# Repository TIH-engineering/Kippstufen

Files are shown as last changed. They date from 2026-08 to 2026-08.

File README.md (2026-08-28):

# Kippstufen






## 🔌 Leiterplattenbeschreibung

Die Leiterplatte **Kippstufen** dient zur Untersuchung verschiedener digitaler Grundschaltungen und Kippstufen. Sie wurde insbesondere für den Einsatz im Elektroniklabor und zur praktischen Ergänzung des Unterrichts entwickelt.

Auf der Leiterplatte sind unterschiedliche Schaltungsvarianten realisiert:

- **diskret aufgebaute Kippstufen** mit Transistoren
- **Kippstufe mit NE555-Timer**
- **bistabile Kippstufe** mit Logik-IC
- **monostabile Kippstufe** mit Logik-IC
- **astabile Kippstufe** mit Logik-IC

Über Taster und Steckverbinder können die Schaltungen angesteuert und unterschiedliche Betriebsarten untersucht werden. LEDs dienen zur optischen Anzeige der jeweiligen Ausgangszustände.

Bei der diskret aufgebauten Kippstufe ermöglichen Jumper die Konfiguration als **bistabile, monostabile oder astabile Kippstufe**. Zusätzlich sind Messanschlüsse vorgesehen, unter anderem zur Untersuchung der Kondensatorspannungen.

Die Leiterplatte eignet sich damit zur praktischen Untersuchung von **Schaltzuständen, Zeitverhalten, Rückkopplung und Oszillation** bei unterschiedlichen Realisierungen von Kippstufen.

> **Einsatzgebiet:** Laborübungen und Unterricht im Bereich Digitaltechnik / Elektronik

---

## 📥 Downloads

| Datei | Beschreibung |
|---|---|
| 📄 [Schaltplan (PDF)](../../releases/latest/download/schematic.pdf) | Schaltplan der Leiterplatte |
| 🖨️ [Leiterplatte (PDF)](../../releases/latest/download/pcb.pdf) | Leiterplattenansicht als PDF |
| 🔩 [Bohrplan (PDF)](../../releases/latest/download/drill.pdf) | Bohrdaten / Bohrplan |
| 📋 [Stückliste (Excel)](../../releases/latest/download/bom.xlsx) | Bill of Materials |
| 🌐 [Interactive BOM](../../releases/latest/download/ibom.html) | Interaktive Bestückungsansicht |
| 📦 [Fertigungsdaten](../../releases/latest/download/kicad.zip) | Gerber- und Bohrdaten |
| 🧊 [STEP-Modell](../../releases/latest/download/pcb.step) | 3D-Modell der Leiterplatte |

Die Dateien werden automatisch durch den Release-Workflow erzeugt.

---

## 🖥️ Leiterplatte

### Vorschau

| Oberseite | Unterseite |
|:---:|:---:|
| PCB Top | PCB Bottom |

### Oberseite

PCB Top

### Unterseite

PCB Bottom

---

## ℹ️ Projektinformationen

| Eigenschaft | Wert |
|---|---|
| **Projekt** | Kippstufen |
| **Software** | KiCad 10 |
| **Repository** | TIH-engineering/Kippstufen |
| **Autor** | TIH |
| **Lizenz** | CC BY-NC-SA 4.0 |

---

## 🗂️ Repository-Struktur

```text
.
├── .github/
│   └── workflows/       # GitHub Actions
├── .kibot/              # KiBot-Konfiguration
├── pcb/
│   ├── lib/             # Projektspezifische Bibliotheken
│   └── ...              # KiCad-Projektdateien
├── .gitignore
├── LICENSE
└── README.md

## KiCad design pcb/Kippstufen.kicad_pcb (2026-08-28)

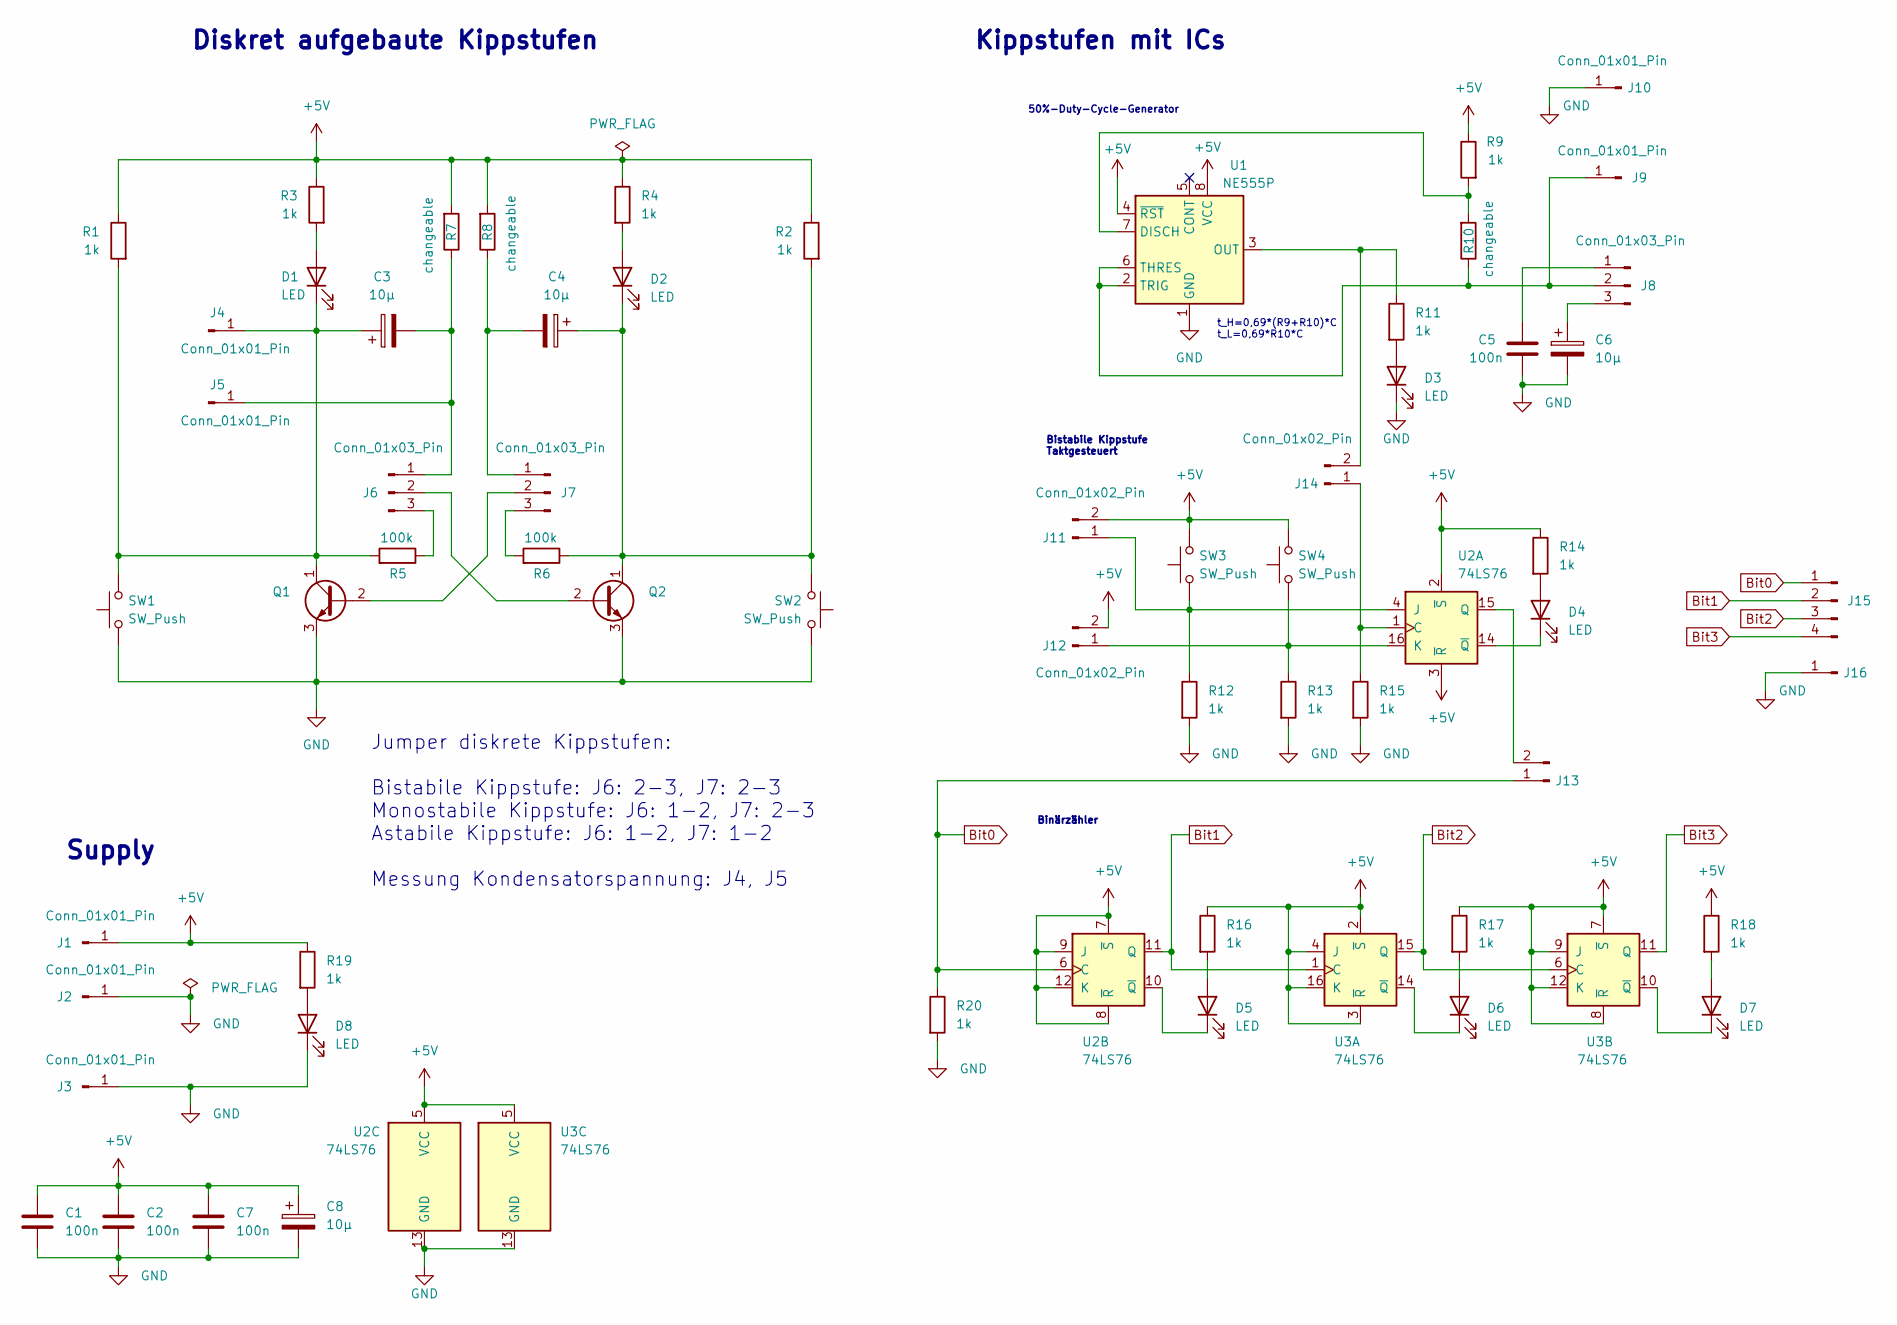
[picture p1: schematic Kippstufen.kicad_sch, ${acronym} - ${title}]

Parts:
C1, C2, C5, C7: 100n; C_1206_3216Metric
C3, C4, C6, C8: 10µ; CP_Radial_D5.0mm_P2.00mm
D1, D2, D3, D4, D5, D6, D7, D8: LED; LED_1206_3216Metric
J1, J2, J3, J4, J5, J9, J10, J16: Conn_01x01_Pin; PinHeader_1x01_P2.54mm_Vertical
J6, J7, J8: Conn_01x03_Pin; PinHeader_1x03_P2.54mm_Vertical
J11, J12, J13, J14: Conn_01x02_Pin; PinHeader_1x02_P2.54mm_Vertical
J15: Conn_01x04_Pin; PinHeader_1x04_P2.54mm_Vertical
Q1, Q2: BC547; TO-92_Inline_Wide
R1, R2, R3, R4, R9, R11, R12, R13, R14, R15, R16, R17, R18, R19, R20: 1k; R_1206_3216Metric
R5, R6: 100k; R_1206_3216Metric
R7, R8, R10: 10k; R_axial_SMD-Adapter_P10.16mm_1mm
SW1, SW2, SW3, SW4: SW_Push; SW_Push_1P1T_NO_E-Switch_TL3301NxxxxxG
U1: NE555P; DIP-8_W7.62mm
U2, U3: 74LS76; DIP-16_W7.62mm

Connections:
+5V: C1.1, C2.1, C7.1, C8.1, J1.1 (Pin_1_1), J11.2, J12.2, R1.1, R2.1, R3.1, R4.1, R7.2, R8.2, R9.1, R14.1, R16.1, R17.1, R18.1, R19.1, SW3.2, SW4.2, U1.4 (~RST), U1.8 (VCC), U2.2 (~S), U2.3 (~R), U2.5 (VCC), U2.7 (~S), U2.8 (~R), U2.9 (J), U2.12 (K), U3.2 (~S), U3.3 (~R), U3.4 (J), U3.5 (VCC), U3.7 (~S), U3.8 (~R), U3.9 (J), U3.12 (K), U3.16 (K)
Bit0: J13.1, J15.1, R20.1, U2.6 (C)
Bit1: J15.2, U2.11 (Q), U3.1 (C)
Bit2: J15.3, U3.6 (C), U3.15 (Q)
Bit3: J15.4, U3.11 (Q)
GND: C1.2, C2.2, C5.2, C6.2, C7.2, C8.2, D3.1 (K), D8.1 (K), J2.1 (Pin_1_1), J3.1 (Pin_1_1), J10.1 (Pin_1_1), J16.1 (Pin_1_1), Q1.3 (E), Q2.3 (E), R12.2, R13.2, R15.2, R20.2, SW1.1, SW2.1, U1.1 (GND), U2.13 (GND), U3.13 (GND)
unnamed: D1.2 (A), R3.2
unnamed: C3.1, D1.1 (K), J4.1 (Pin_1_1), Q1.1 (C), R1.2, R5.2, SW1.2
unnamed: D2.2 (A), R4.2
unnamed: C4.1, D2.1 (K), Q2.1 (C), R2.2, R6.1, SW2.2
unnamed: D3.2 (A), R11.2
unnamed: D4.2 (A), R14.2
unnamed: D4.1 (K), U2.14 (~Q)
unnamed: D5.2 (A), R16.2
unnamed: D5.1 (K), U2.10 (~Q)
unnamed: D6.2 (A), R17.2
unnamed: D6.1 (K), U3.14 (~Q)
unnamed: D7.2 (A), R18.2
unnamed: D7.1 (K), U3.10 (~Q)
unnamed: D8.2 (A), R19.2
unnamed: C3.2, J5.1 (Pin_1_1), J6.1, R7.1
unnamed: J6.2, Q2.2 (B)
unnamed: J6.3, R5.1
unnamed: C4.2, J7.1, R8.1
unnamed: J7.2, Q1.2 (B)
unnamed: J7.3, R6.2
unnamed: C5.1, J8.1
unnamed: J8.2, J9.1 (Pin_1_1), R10.1, U1.2 (TRIG), U1.6 (THRES)
unnamed: C6.1, J8.3
unnamed: J11.1, R12.1, SW3.1, U2.4 (J)
unnamed: J12.1, R13.1, SW4.1, U2.16 (K)
unnamed: J13.2, U2.15 (Q)
unnamed: J14.1, R15.1, U2.1 (C)
unnamed: J14.2, R11.1, U1.3 (OUT)
unnamed: R9.2, R10.2, U1.7 (DISCH)

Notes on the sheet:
Bistabile Kippstufe Taktgesteuert
Binärzähler
Supply
t_H=0,69*(R9+R10)*C t_L=0,69*R10*C
50%-Duty-Cycle-Generator
Jumper diskrete Kippstufen: Bistabile Kippstufe: J6: 2-3, J7: 2-3 Monostabile Kippstufe: J6: 1-2, J7: 2-3 Astabile Kippstufe: J6: 1-2, J7: 1-2 Messung Kondensatorspannung: J4, J5
Diskret aufgebaute Kippstufen
Kippstufen mit ICs

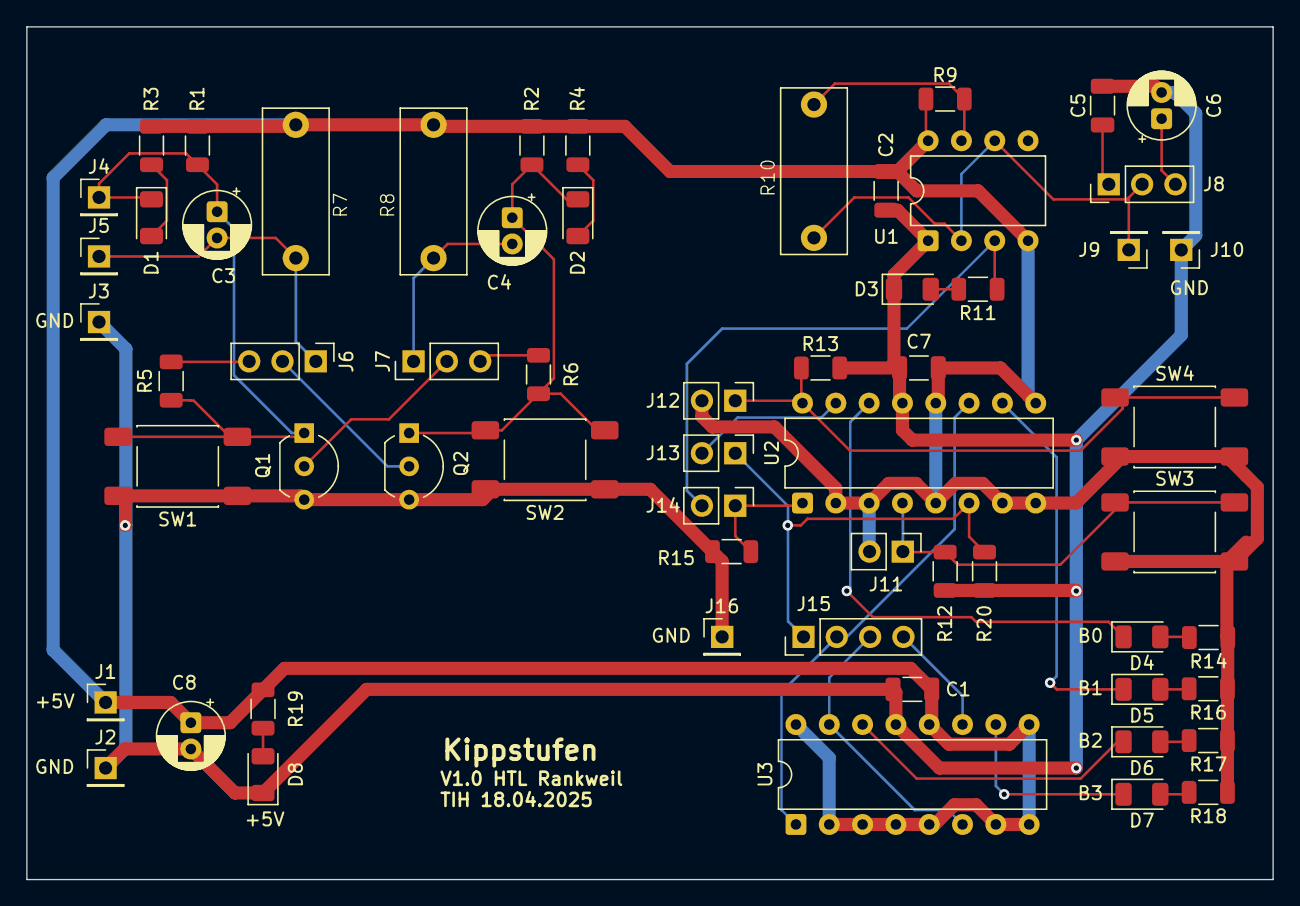
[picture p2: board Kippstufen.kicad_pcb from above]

Board: 2 copper layers, 95.0 x 65.0 mm, 61 parts (0 on the bottom side), 35 nets.

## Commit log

2026-08-28 PCB migrated in KiCad-Template
    [Kippstufen.kicad_pcb, Kippstufen.kicad_sch, Template.kicad_pcb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]
2026-08-28 PCB Warnings fixed
    [Kippstufen.kicad_pcb, Kippstufen.kicad_sch]

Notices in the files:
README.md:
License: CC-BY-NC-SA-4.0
